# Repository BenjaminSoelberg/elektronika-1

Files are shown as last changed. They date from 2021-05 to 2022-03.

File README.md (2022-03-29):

# ELEKTRONIKA-1 - A replacement module for a USSR made vintage LED watch anno 1978

## It actually works
The watch works very well and I am very happy with it.

It has been my daily driver for a few months by now with no problems what so ever.

It can show time, date and year which was more or less what you got in the original.

The module is based around:
* Texas Instruments MSP430fr2433 micro controller
* Austria Micro Systems AS1115 64 bit LED driver
* Vintage Hewlett Packard HP-5082-7414 4x7 segments + dot display
* CR2032 battery

## Source code
Modules:

* buttons.c - This is the button driver and it handles button events 
* clocksystem.c - Initializes the clock system in the MSP430
* config.h - Global timing and clock constants
* debounce.c - The button debounce detection and filtering using a sliding bit buffer
* display.c - Display update functions like content and intensity.
* driverlib_ng.c - My overloading of the TI MSP430 driver lib for better pin handling
* elektronika.c - Handles the control flow of everything
* render.c - Simple 7 segment 'font' driver
* rtcclock.c - Realtime clock module supporting adjusting date and time
* utils.h - Macros for entering and exiting critical sections

Written using Code Composer Studio.

## Hardware

The PCB is designed in KiCad and is my first ever multi layer PCB.

Button contacts are made with what would normally be plated half castellated holes but they are in reality nothing more than partially routed mounting holes.

The AS1115 display driver was choosen as it is able to drive the LED display directly as well as adjusting the current.

A lot of care has been taken to save as much power as possible.  Battery life is messured to be around 10 years (less if you actually press buttons as the LED technology from the late 1970 uses a lot of current).

The watch uses around 0.002 mA/h in standby and 10-40 mA/h while the display is on.

Originally the two 1.55 V batteries didn't even last a year.

Schematics:

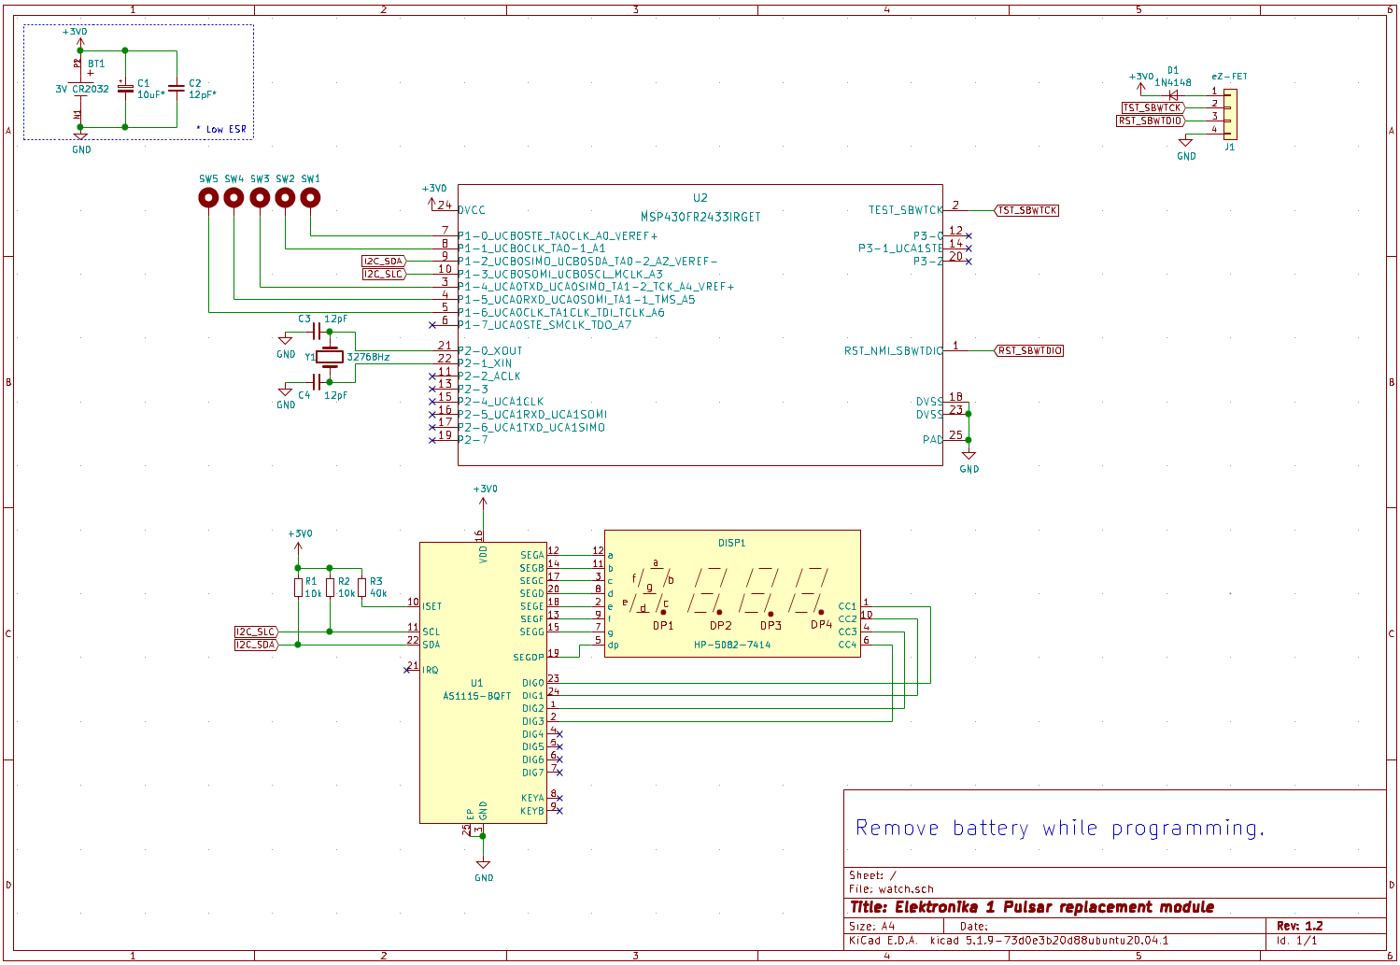
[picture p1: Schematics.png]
Schematics


The four PCB layers:

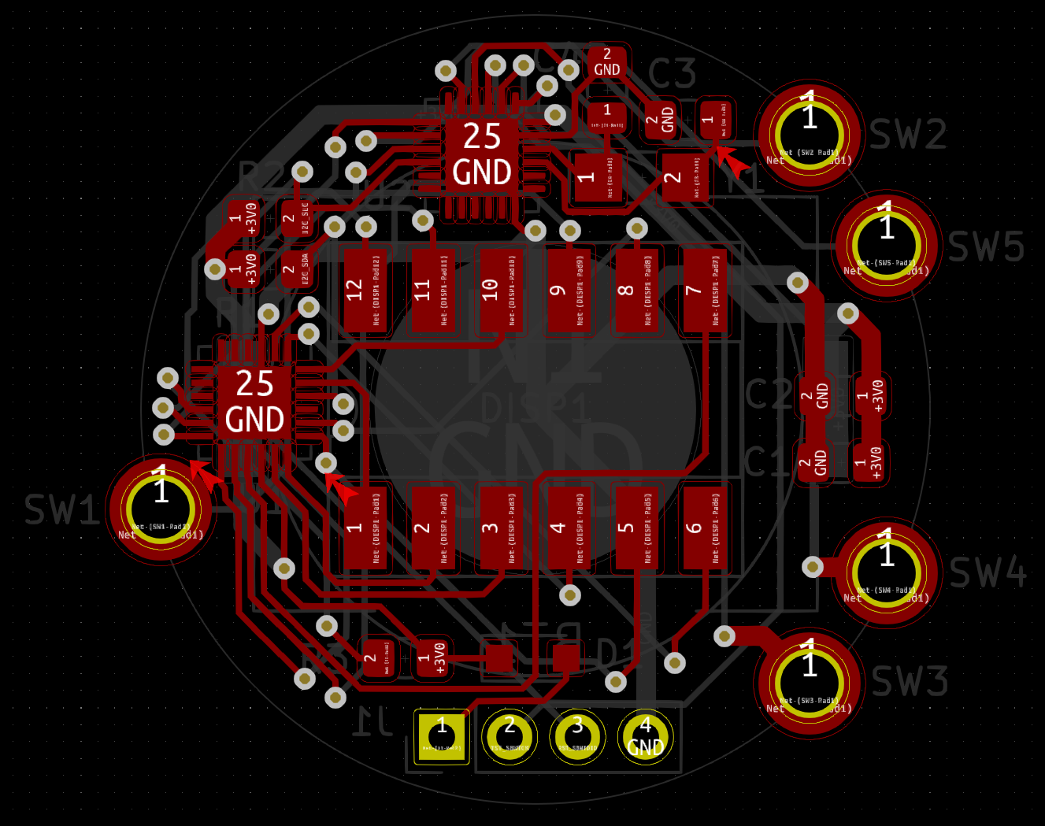
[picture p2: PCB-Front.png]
The four PCB layers


3D render of front PCB:

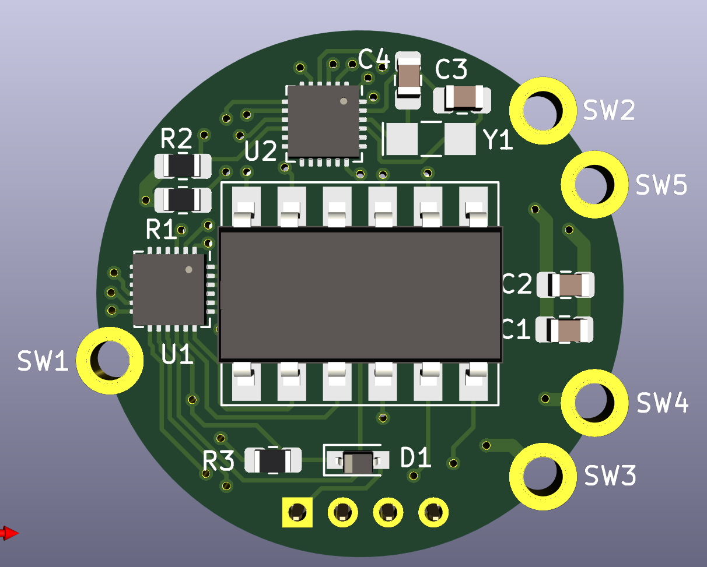
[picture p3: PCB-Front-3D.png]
3D render of front PCB


3D render of back PCB:

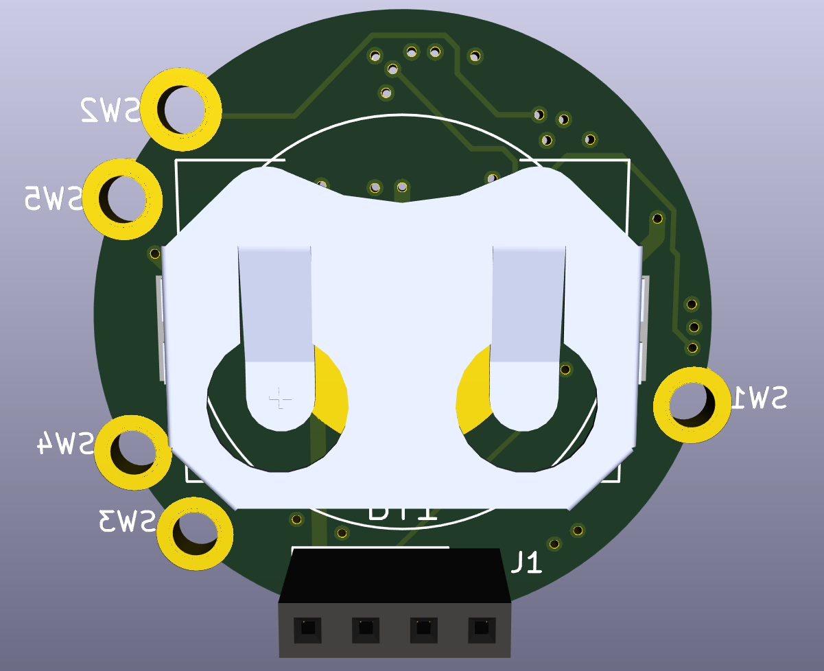
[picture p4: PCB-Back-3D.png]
3D render of back PCB


What the original module looks like:

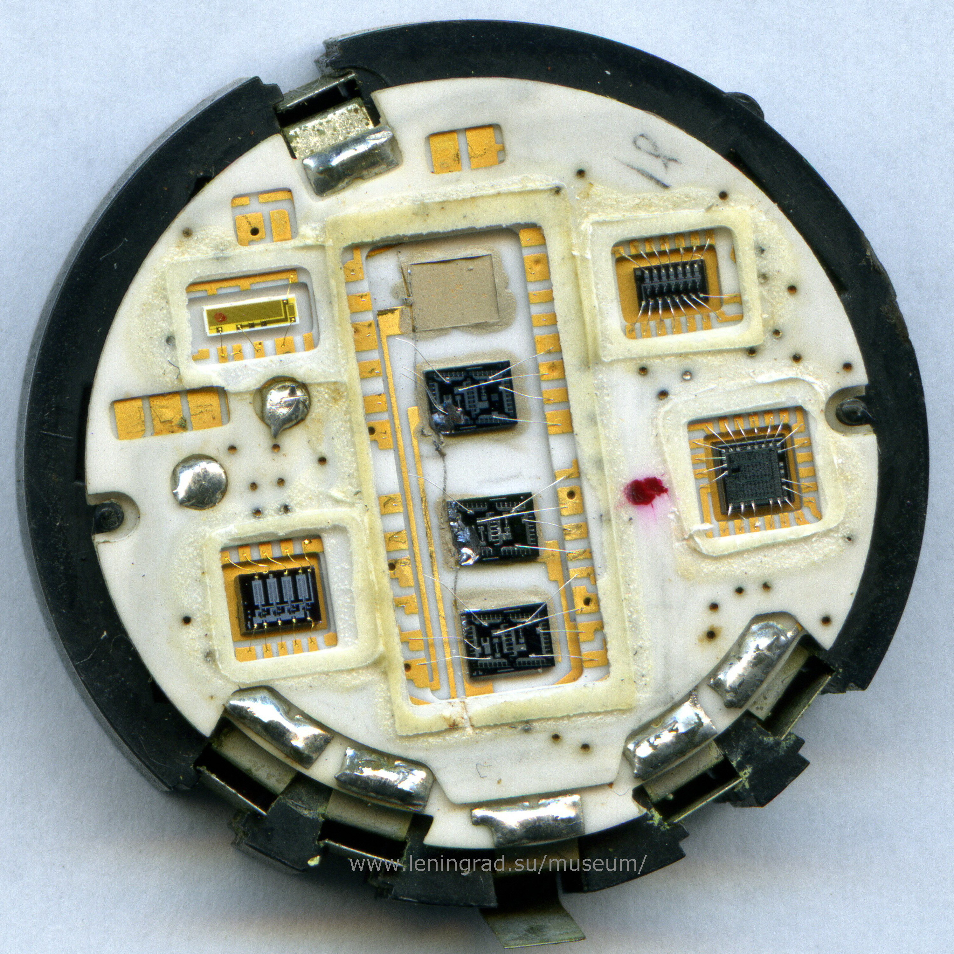
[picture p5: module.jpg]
Original module


New watch module:

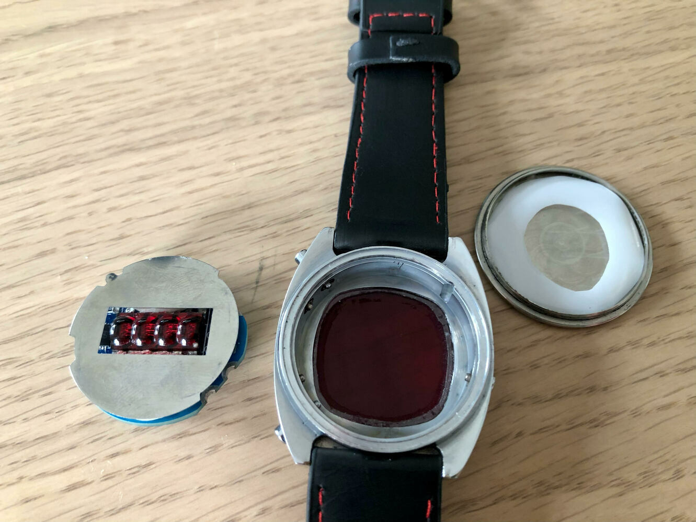
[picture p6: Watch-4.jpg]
Dissambled


New watch module installed:

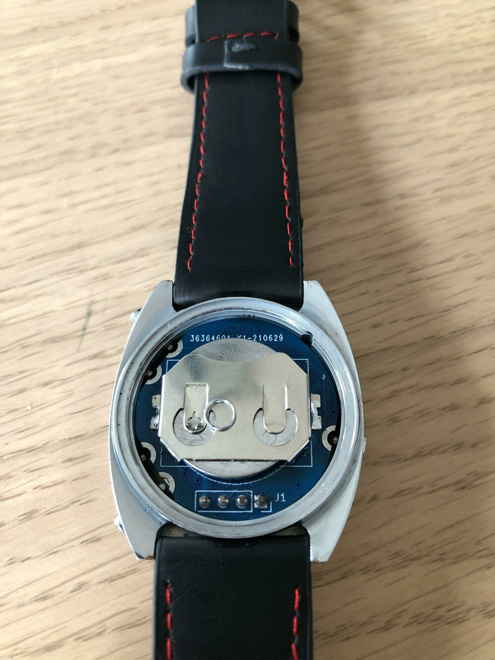
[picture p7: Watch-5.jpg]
New watch module


Showing time:

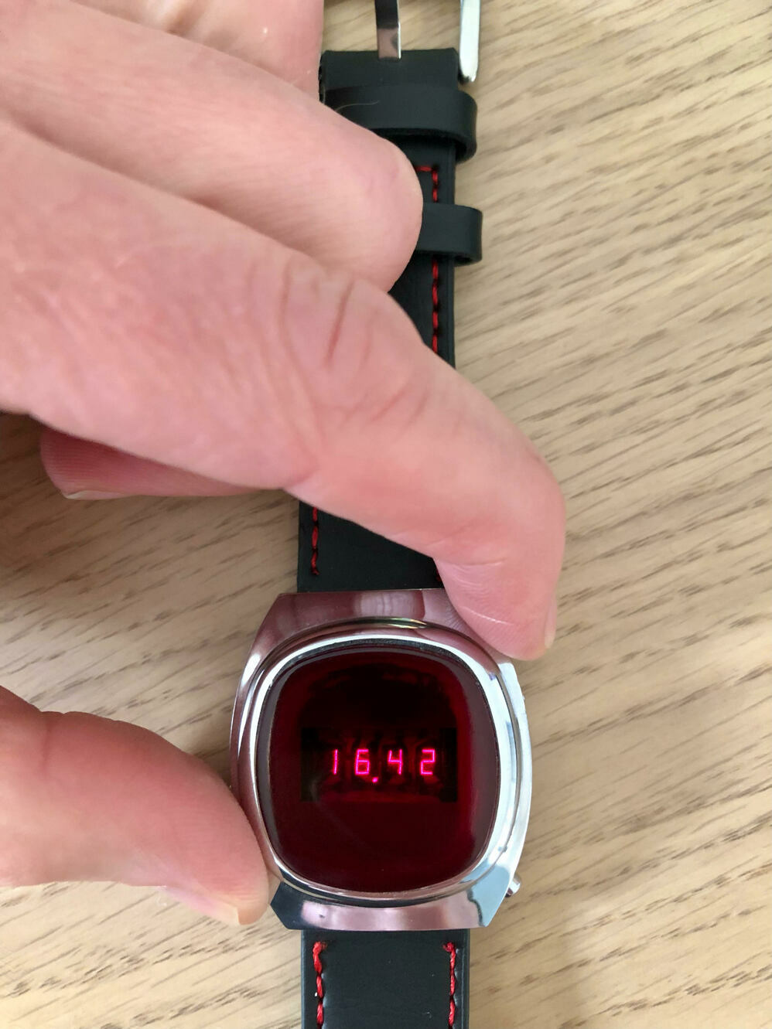
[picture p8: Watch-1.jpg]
Showing time


Showning date:

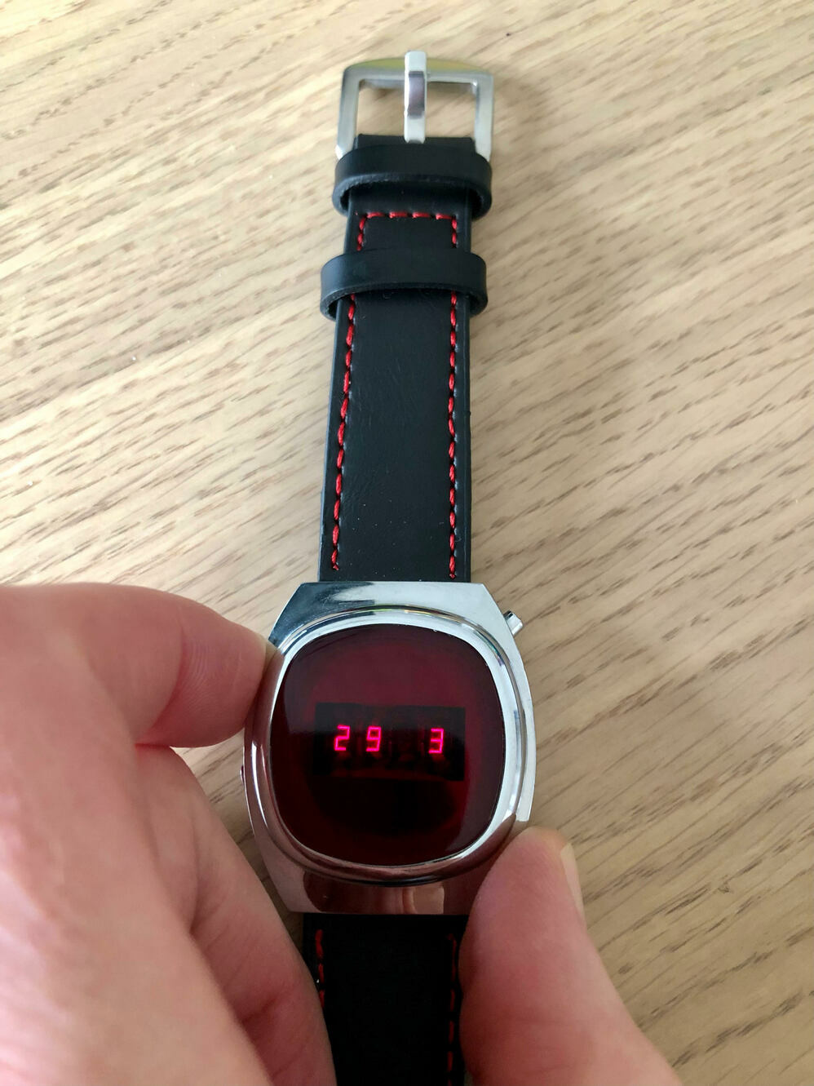
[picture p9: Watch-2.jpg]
Showning date


On wrist:

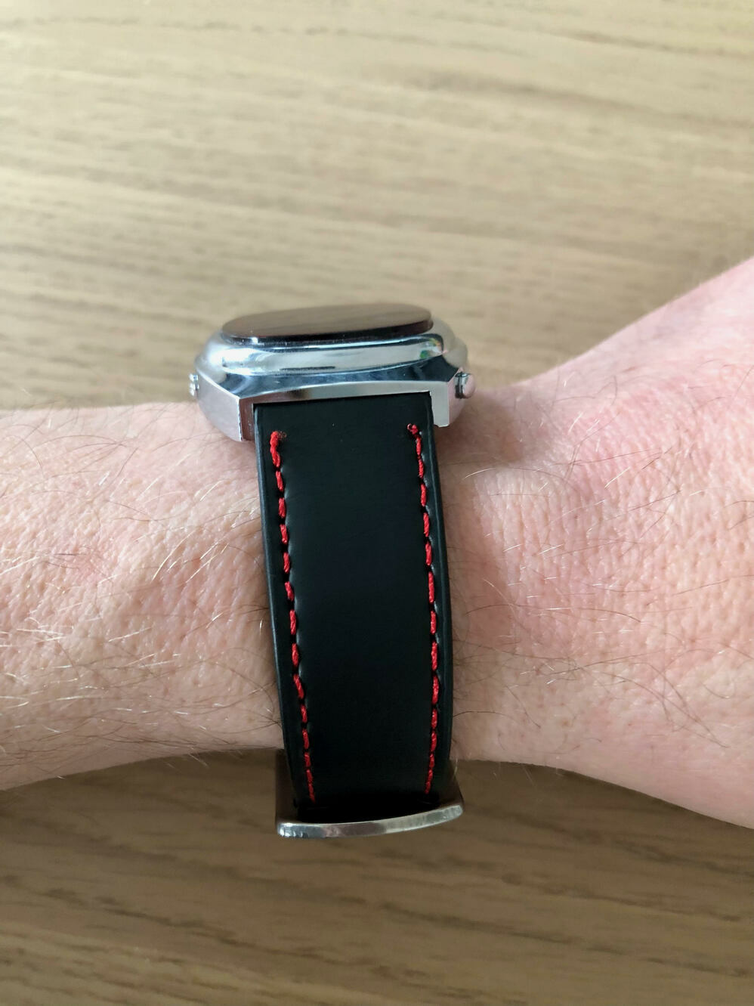
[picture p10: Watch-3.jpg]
On wrist


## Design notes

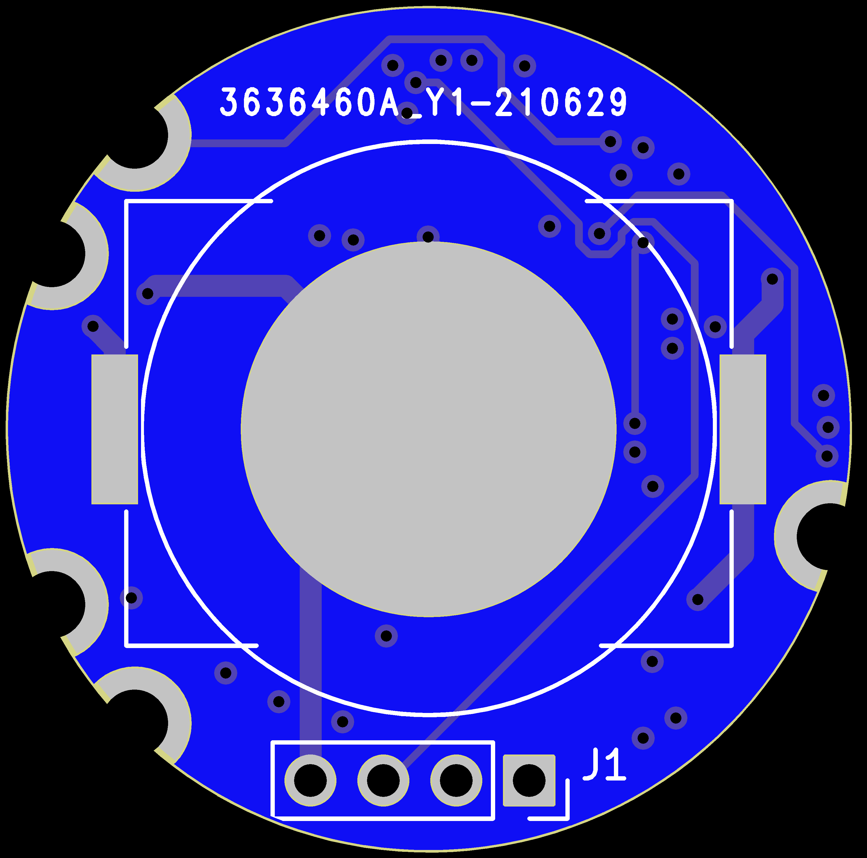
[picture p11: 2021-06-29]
JLCPCB/from-jlcpcb/jlc-back.png

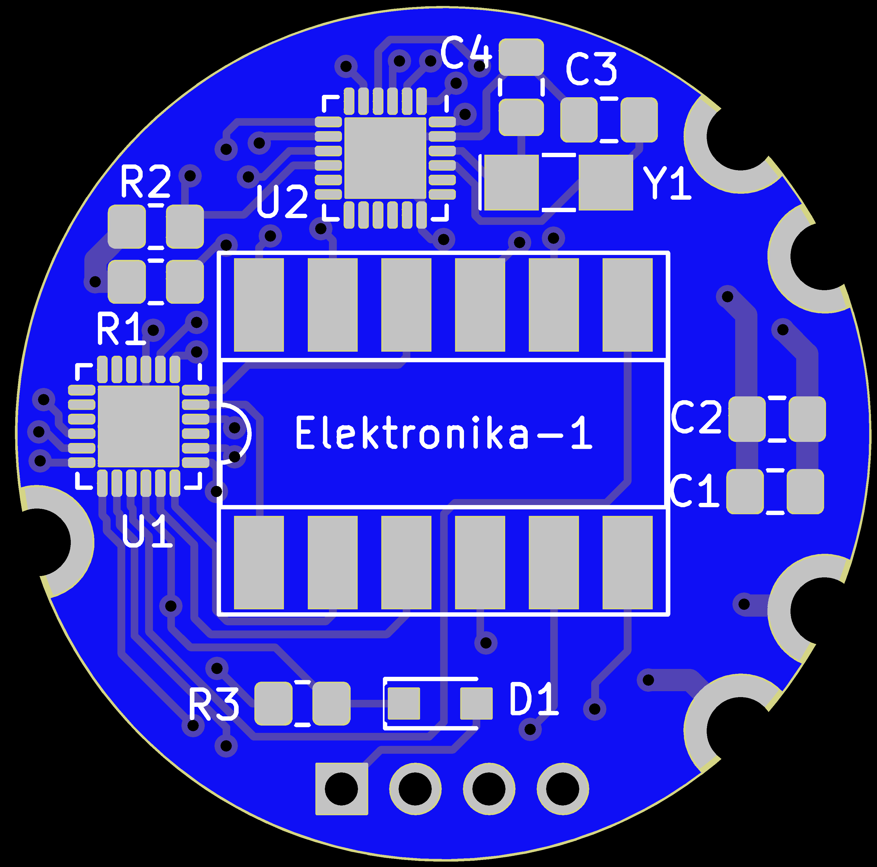
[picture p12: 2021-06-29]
JLCPCB/from-jlcpcb/jlc-front.png

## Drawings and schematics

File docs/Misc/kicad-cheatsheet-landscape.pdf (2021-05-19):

# cheatsheet

## 3) Create new components as necessary

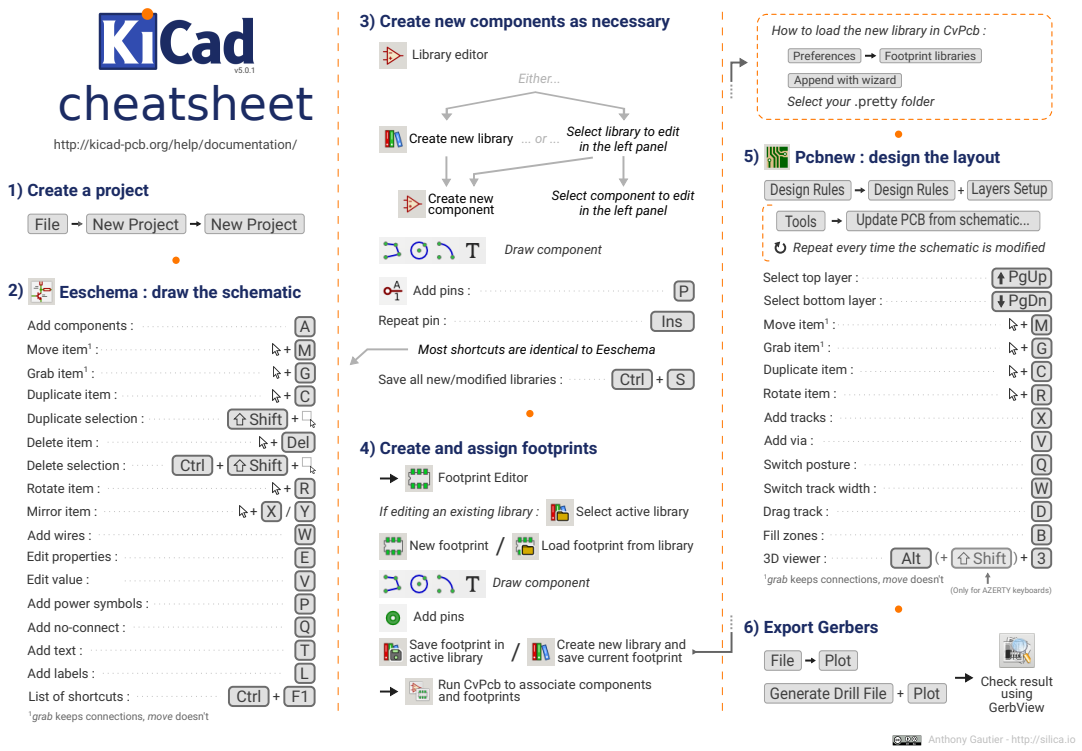
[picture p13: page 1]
1) Create a project; File; New Project; Add components :; Duplicate item :; Duplicate selection :; Shift +; Delete item :; + Del; Delete selection :; Ctrl; Shift ++; Rotate item :; Mirror item :; Add wires :; Edit properties :; Add power symbols :; Add no-connect :; Add text :; Add labels :; List of shortcuts :; Ctrl + F1; Edit value :; Draw component; Library editor; Repeat pin :; Ins; Save all new/modified libraries :; Ctrl + S; Create new component; Add pins :; Either...; Footprint Editor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

How to load the new library in CvPcb :
Append with wizard
Select your .pretty folder

Select library to edit

in the left panel Create new library

http://kicad-pcb.org/help/documentation/

5) Pcbnew : design the layout
Repeat every time the schematic is modified
Select top layer :
Move item¹
Grab item¹
Duplicate item :
Rotate item :
Add tracks :
Add via :
Switch posture :
Switch track width :
Drag track :
Fill zones :
3D viewer :
grab keeps connections, move doesn't

Select component to edit
in the left panel

2) Eeschema : draw the schematic

Most shortcuts are identical to Eeschema

4) Create and assign footprints

New footprint / Load footprint from library

(Only for AZERTY keyboards)

Add pins
Create new library and / save current footprint Save footprint in
active library
Run CvPcb to associate components
and footprints

6) Export Gerbers
Generate Drill File + Plot

Anthony Gautier - http://silica.io

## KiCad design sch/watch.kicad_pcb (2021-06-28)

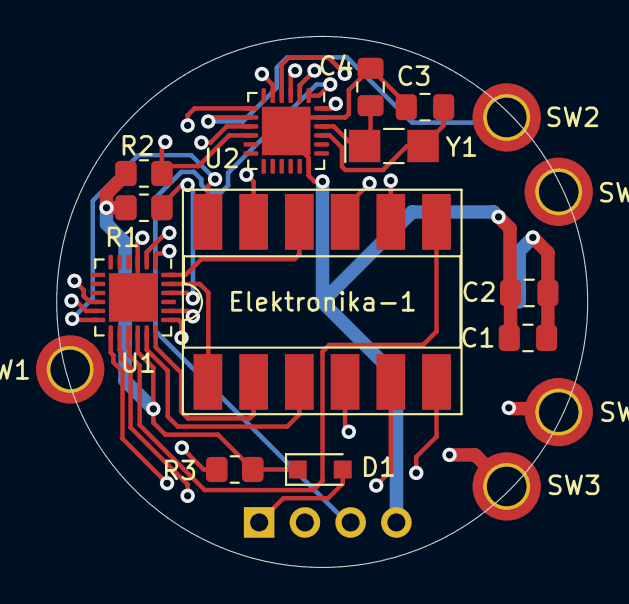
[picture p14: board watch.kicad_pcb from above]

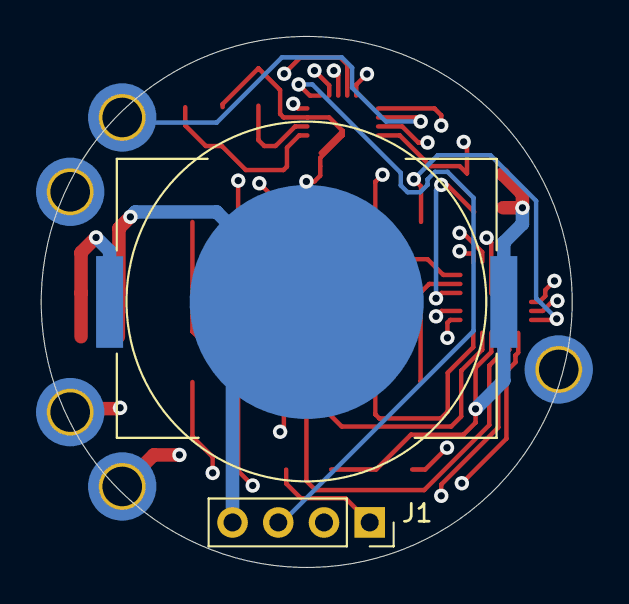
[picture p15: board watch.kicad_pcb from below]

Board: 4 copper layers, 29.5 x 29.5 mm, 19 parts (2 on the bottom side), 27 nets.

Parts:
BT1: 3V CR2032; BAT-HLD-001
C1: 10uF*; C_0805_2012Metric_Pad1.18x1.45mm_HandSolder
C2: 12pF*; C_0805_2012Metric_Pad1.18x1.45mm_HandSolder
C3, C4: 12pF; C_0805_2012Metric_Pad1.18x1.45mm_HandSolder
D1: 1N4148; D_SOD-323_HandSoldering
Elektronika-1: HP-5082-7414; DIP-12_W8.89mm_SMDSocket_LongPads
J1: eZ-FET; PinSocket_1x04_P2.54mm_Vertical
R1, R2: 10k; R_0805_2012Metric_Pad1.20x1.40mm_HandSolder
R3: 40k; R_0805_2012Metric_Pad1.20x1.40mm_HandSolder
SW1: SW1; MountingHole_2.2mm_M2_DIN965_Pad_TopBottom
SW2: SW2; MountingHole_2.2mm_M2_DIN965_Pad_TopBottom
SW3: SW3; MountingHole_2.2mm_M2_DIN965_Pad_TopBottom
SW4: SW4; MountingHole_2.2mm_M2_DIN965_Pad_TopBottom
SW5: SW5; MountingHole_2.2mm_M2_DIN965_Pad_TopBottom
U1: AS1115; QFN-24-1EP_4x4mm_P0.5mm_EP2.7x2.7mm
U2: MSP430FR2433; QFN-24-1EP_4x4mm_P0.5mm_EP2.7x2.7mm
Y1: 32768Hz; Crystal_SMD_MicroCrystal_CC7V-T1A-2Pin_3.2x1.5mm_HandSolder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

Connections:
+3V0: BT1.P1, BT1.P2, C1.1, C2.1, D1.1, R1.1, R2.1, R3.1, U1.16, U2.24
GND: BT1.N1, C1.2, C2.2, C3.2, C4.2, J1.4, U1.3, U1.25, U2.18, U2.23, U2.25
I2C_SDA: R1.2, U1.22, U2.9
I2C_SLC: R2.2, U1.11, U2.10
unnamed: C3.1, U2.21, Y1.2
unnamed: C4.1, U2.22, Y1.1
unnamed: D1.2, J1.1
unnamed: Elektronika-1.1, U1.23
unnamed: Elektronika-1.2, U1.18
unnamed: Elektronika-1.3, U1.17
unnamed: Elektronika-1.4, U1.1
unnamed: Elektronika-1.5, U1.19
unnamed: Elektronika-1.6, U1.2
unnamed: Elektronika-1.7, U1.15
unnamed: Elektronika-1.8, U1.20
unnamed: Elektronika-1.9, U1.13
unnamed: Elektronika-1.10, U1.24
unnamed: Elektronika-1.11, U1.14
unnamed: Elektronika-1.12, U1.12
unnamed: R3.2, U1.10
unnamed: SW1.1, U2.7
unnamed: SW2.1, U2.8
unnamed: SW3.1, U2.3
unnamed: SW4.1, U2.4
unnamed: SW5.1, U2.5
RST_SBWTDIO: J1.3, U2.1
TST_SBWTCK: J1.2, U2.2

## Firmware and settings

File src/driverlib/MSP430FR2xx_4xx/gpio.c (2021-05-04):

//*****************************************************************************
//
// gpio.c - Driver for the gpio Module.
//
//*****************************************************************************

//*****************************************************************************
//
//! \addtogroup gpio_api gpio
//! @{
//
//*****************************************************************************

#include "inc/hw_memmap.h"

#if defined(__MSP430_HAS_PORT1_R__) || defined(__MSP430_HAS_PORT2_R__) ||\
    defined(__MSP430_HAS_PORTA_R__)
#include "gpio.h"

#include <assert.h>

static const uint16_t GPIO_PORT_TO_BASE[] = {
    0x00,
#if defined(__MSP430_HAS_PORT1_R__)
    __MSP430_BASEADDRESS_PORT1_R__,
#elif defined(__MSP430_HAS_PORT1__)
    __MSP430_BASEADDRESS_PORT1__,
#else
    0xFFFF,
#endif
#if defined(__MSP430_HAS_PORT2_R__)
    __MSP430_BASEADDRESS_PORT2_R__,
#elif defined(__MSP430_HAS_PORT2__)
    __MSP430_BASEADDRESS_PORT2__,
#else
    0xFFFF,
#endif
#if defined(__MSP430_HAS_PORT3_R__)
    __MSP430_BASEADDRESS_PORT3_R__,
#elif defined(__MSP430_HAS_PORT3__)
    __MSP430_BASEADDRESS_PORT3__,
#else
    0xFFFF,
#endif
#if defined(__MSP430_HAS_PORT4_R__)
    __MSP430_BASEADDRESS_PORT4_R__,
#elif defined(__MSP430_HAS_PORT4__)
    __MSP430_BASEADDRESS_PORT4__,
#else
    0xFFFF,
#endif
#if defined(__MSP430_HAS_PORT5_R__)
    __MSP430_BASEADDRESS_PORT5_R__,
#elif defined(__MSP430_HAS_PORT5__)
    __MSP430_BASEADDRESS_PORT5__,
#else
    0xFFFF,
#endif
#if defined(__MSP430_HAS_PORT6_R__)
    __MSP430_BASEADDRESS_PORT6_R__,
#elif defined(__MSP430_HAS_PORT6__)
    __MSP430_BASEADDRESS_PORT6__,
#else
    0xFFFF,
#endif
#if defined(__MSP430_HAS_PORT7_R__)
    __MSP430_BASEADDRESS_PORT7_R__,
#elif defined(__MSP430_HAS_PORT7__)
    __MSP430_BASEADDRESS_PORT7__,
#else
    0xFFFF,
#endif
#if defined(__MSP430_HAS_PORT8_R__)
    __MSP430_BASEADDRESS_PORT8_R__,
#elif defined(__MSP430_HAS_PORT8__)
    __MSP430_BASEADDRESS_PORT8__,
#else
    0xFFFF,
#endif
#if defined(__MSP430_HAS_PORT9_R__)
    __MSP430_BASEADDRESS_PORT9_R__,
#elif defined(__MSP430_HAS_PORT9__)
    __MSP430_BASEADDRESS_PORT9__,
#else
    0xFFFF,
#endif
#if defined(__MSP430_HAS_PORT10_R__)
    __MSP430_BASEADDRESS_PORT10_R__,
#elif defined(__MSP430_HAS_PORT10__)
    __MSP430_BASEADDRESS_PORT10__,
#else
    0xFFFF,
#endif
#if defined(__MSP430_HAS_PORT11_R__)
    __MSP430_BASEADDRESS_PORT11_R__,
#elif defined(__MSP430_HAS_PORT11__)
    __MSP430_BASEADDRESS_PORT11__,
#else
    0xFFFF,
#endif
    0xFFFF,
#if defined(__MSP430_HAS_PORTJ_R__)
    __MSP430_BASEADDRESS_PORTJ_R__
#elif defined(__MSP430_HAS_PORTJ__)
    __MSP430_BASEADDRESS_PORTJ__
#else
    0xFFFF
#endif
};

void GPIO_setAsOutputPin(uint8_t selectedPort, uint16_t selectedPins) {

    uint16_t baseAddress = GPIO_PORT_TO_BASE[selectedPort];

    #ifndef NDEBUG
    if(baseAddress == 0xFFFF) {
        return;
    }
    #endif

    // Shift by 8 if port is even (upper 8-bits)
    if((selectedPort & 1) ^ 1) {
        selectedPins <<= 8;
    }

#ifdef __MSP430_HAS_PASEL0__
    HWREG16(baseAddress + OFS_PASEL0) &= ~selectedPins;
#endif
#ifdef __MSP430_HAS_PASEL1__
    HWREG16(baseAddress + OFS_PASEL1) &= ~selectedPins;
#endif
    HWREG16(baseAddress + OFS_PADIR) |= selectedPins;

    return;
}

void GPIO_setAsInputPin(uint8_t selectedPort, uint16_t selectedPins) {

    uint16_t baseAddress = GPIO_PORT_TO_BASE[selectedPort];

    #ifndef NDEBUG
    if(baseAddress == 0xFFFF) {
        return;
    }
    #endif

    // Shift by 8 if port is even (upper 8-bits)
    if((selectedPort & 1) ^ 1) {
        selectedPins <<= 8;
    }

#ifdef __MSP430_HAS_PASEL0__
    HWREG16(baseAddress + OFS_PASEL0) &= ~selectedPins;
#endif
#ifdef __MSP430_HAS_PASEL1__
    HWREG16(baseAddress + OFS_PASEL1) &= ~selectedPins;
#endif
    HWREG16(baseAddress + OFS_PADIR) &= ~selectedPins;
    HWREG16(baseAddress + OFS_PAREN) &= ~selectedPins;
}
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

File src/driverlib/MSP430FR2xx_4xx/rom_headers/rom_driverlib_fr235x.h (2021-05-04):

//*****************************************************************************
//
// rom_driverlib_fr235x.h - Macros to facilitate calling functions in ROM for
// MSP430FR2355, FR2353, FR2153, FR2155
//
// Copyright (c) 2017 Texas Instruments Incorporated.  All rights reserved.
// TI Information - Selective Disclosure
//
//*****************************************************************************
//

#if defined(__TI_COMPILER_VERSION__)
#if __TI_COMPILER_VERSION__ >= 18001001
#define __cc_rom __attribute__((call_conv("cc_rom")))
#else
#error "The cc_rom attribute requires MSP TI COMPILER 18.1.1.LTS or more recent."
#endif  // __TI_COMPILER_VERSION__ >= 
#endif  // (defined(__TI_COMPILER_VERSION__))18001001

#if defined(__IAR_SYSTEMS_ICC__) && (__VER__ < 650)
#error "The __cc_rom attribute requires IAR version 6.50 or more recent."
#endif

#if __REGISTER_R4__ != __REGISTER_FREE__
#error "Incorrect setting for R4, expected it to be free."
#endif

#if __REGISTER_R5__ != __REGISTER_FREE__
#error "Incorrect setting for R5, expected it to be free."
#endif

// Suppress type conversion warning
#ifdef __TI_COMPILER_VERSION__
#pragma diag_suppress 173
#endif

#if (defined(__TI_COMPILER_VERSION__) && !defined(__LARGE_DATA_MODEL__)) || \
(defined(__IAR_SYSTEMS_ICC__) && (__DATA_MODEL__!=__DATA_MODEL_LARGE__))
#error "Only large data model supported for this ROM."
#endif

#ifndef __ROM_DRIVERLIB_H__
#define __ROM_DRIVERLIB_H__

#if (defined(__TI_COMPILER_VERSION__) && defined(__LARGE_CODE_MODEL__)) || \
    (defined(__IAR_SYSTEMS_ICC__) && (__CODE_MODEL__==__CODE_MODEL_LARGE__))

//*****************************************************************************
//
// Pointers to the main API tables.
//
//*****************************************************************************
#ifndef ROM_TABLE
#define ROM_TABLE                      ((uint32_t *)ROMLIB_START)
#endif
#define ROM_DRIVERLIB_APITABLE         ((uint32_t *)&ROM_TABLE[2])
#define ROM_DRIVERLIB_VERSIONL         (ROM_DRIVERLIB_APITABLE[0])
#define ROM_DRIVERLIB_VERSIONH         (ROM_DRIVERLIB_APITABLE[1])
#define ROM_ADCTABLE                   ((uint32_t *)(ROM_DRIVERLIB_APITABLE[2]))
#define ROM_CRCTABLE                   ((uint32_t *)(ROM_DRIVERLIB_APITABLE[3]))
#define ROM_CSTABLE                    ((uint32_t *)(ROM_DRIVERLIB_APITABLE[4]))
#define ROM_ECOMPTABLE                 ((uint32_t *)(ROM_DRIVERLIB_APITABLE[5]))
#define ROM_EUSCIASPITABLE             ((uint32_t *)(ROM_DRIVERLIB_APITABLE[6]))
#define ROM_EUSCIAUARTTABLE            ((uint32_t *)(ROM_DRIVERLIB_APITABLE[7]))
#define ROM_EUSCIBI2CTABLE             ((uint32_t *)(ROM_DRIVERLIB_APITABLE[8]))
#define ROM_EUSCIBSPITABLE             ((uint32_t *)(ROM_DRIVERLIB_APITABLE[9]))
#define ROM_FRAMCTLTABLE               ((uint32_t *)(ROM_DRIVERLIB_APITABLE[10]))
#define ROM_GPIOTABLE                  ((uint32_t *)(ROM_DRIVERLIB_APITABLE[11]))
#define ROM_ICCTABLE                   ((uint32_t *)(ROM_DRIVERLIB_APITABLE[12]))
#define ROM_MPY32TABLE                 ((uint32_t *)(ROM_DRIVERLIB_APITABLE[14]))
#define ROM_PMMTABLE                   ((uint32_t *)(ROM_DRIVERLIB_APITABLE[15]))
#define ROM_RTCTABLE                   ((uint32_t *)(ROM_DRIVERLIB_APITABLE[16]))
#define ROM_SACTABLE                   ((uint32_t *)(ROM_DRIVERLIB_APITABLE[17]))
#define ROM_SFRTABLE                   ((uint32_t *)(ROM_DRIVERLIB_APITABLE[18]))
#define ROM_SYSCTLTABLE                ((uint32_t *)(ROM_DRIVERLIB_APITABLE[19]))
#define ROM_TIMER_BTABLE               ((uint32_t *)(ROM_DRIVERLIB_APITABLE[22]))
#define ROM_TLVTABLE                   ((uint32_t *)(ROM_DRIVERLIB_APITABLE[23]))
#define ROM_WDTATABLE                  ((uint32_t *)(ROM_DRIVERLIB_APITABLE[24]))

#define ROM_DRIVERLIB_getVersion()     ((uint32_t)ROM_DRIVERLIB_VERSIONH<<16|\
                                            ROM_DRIVERLIB_VERSIONL)
#ifndef ROM_getVersion
#define ROM_getVersion()               ((uint32_t)(ROMLIB_START[0]))
#endif

//*****************************************************************************
//
// Macros for calling ROM functions in the ADC API.
//
//*****************************************************************************

#define ROM_ADC_init                                                          \
        ((void ( __cc_rom *)(uint16_t baseAddress,                            \
                             uint16_t sampleHoldSignalSourceSelect,           \
                             uint8_t clockSourceSelect,                       \
                             uint16_t clockSourceDivider))ROM_ADCTABLE[0])

#define ROM_ADC_enable                                                        \
        ((void ( __cc_rom *)(uint16_t baseAddress))ROM_ADCTABLE[1])

#define ROM_ADC_disable                                                       \
        ((void ( __cc_rom *)(uint16_t baseAddress))ROM_ADCTABLE[2])

#define ROM_ADC_setupSamplingTimer                                            \
        ((void ( __cc_rom *)(uint16_t baseAddress,                            \
                             uint16_t clockCycleHoldCount,                    \
                             uint16_t multipleSamplesEnabled))ROM_ADCTABLE[3])

#define ROM_ADC_disableSamplingTimer                                          \
        ((void ( __cc_rom *)(uint16_t baseAddress))ROM_ADCTABLE[4])

#define ROM_ADC_configureMemory                                               \
        ((void ( __cc_rom *)(uint16_t baseAddress,                            \
                             uint8_t inputSourceSelect,                       \
                             uint8_t positiveRefVoltageSourceSelect,          \
                             uint8_t negativeRefVoltageSourceSelect))ROM_ADCTABLE[5])

#define ROM_ADC_enableInterrupt                                               \
        ((void ( __cc_rom *)(uint16_t baseAddress,                            \
                             uint8_t interruptMask))ROM_ADCTABLE[6])

#define ROM_ADC_disableInterrupt                                              \
        ((void ( __cc_rom *)(uint16_t baseAddress,                            \
                             uint8_t interruptMask))ROM_ADCTABLE[7])

#define ROM_ADC_clearInterrupt                                                \
        ((void ( __cc_rom *)(uint16_t baseAddress,                            \
                             uint8_t interruptFlagMask))ROM_ADCTABLE[8])

#define ROM_ADC_getInterruptStatus                                            \
        ((uint8_t ( __cc_rom *)(uint16_t baseAddress,                         \
                                uint8_t interruptFlagMask))ROM_ADCTABLE[9])

#define ROM_ADC_startConversion                                               \
        ((void ( __cc_rom *)(uint16_t baseAddress,                            \
                             uint8_t conversionSequenceModeSelect))ROM_ADCTABLE[10])
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

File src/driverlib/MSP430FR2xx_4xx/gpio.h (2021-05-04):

//*****************************************************************************
//
// gpio.h - Driver for the GPIO Module.
//
//*****************************************************************************

#ifndef __MSP430WARE_GPIO_H__
#define __MSP430WARE_GPIO_H__

#include "inc/hw_memmap.h"

#if defined(__MSP430_HAS_PORT1_R__) || defined(__MSP430_HAS_PORT2_R__) ||\
    defined(__MSP430_HAS_PORTA_R__)

//*****************************************************************************
//
// If building with a C++ compiler, make all of the definitions in this header
// have a C binding.
//
//*****************************************************************************
#ifdef __cplusplus
extern "C"
{
#endif

//*****************************************************************************
//
// The following are values that can be passed to the selectedPort parameter
// for functions: GPIO_setAsOutputPin(), GPIO_setAsInputPin(),
// GPIO_setAsPeripheralModuleFunctionOutputPin(),
// GPIO_setAsPeripheralModuleFunctionInputPin(), GPIO_setOutputHighOnPin(),
// GPIO_setOutputLowOnPin(), GPIO_toggleOutputOnPin(),
// GPIO_setAsInputPinWithPullDownResistor(),
// GPIO_setAsInputPinWithPullUpResistor(), GPIO_getInputPinValue(),
// GPIO_selectInterruptEdge(), GPIO_enableInterrupt(), GPIO_disableInterrupt(),
// GPIO_getInterruptStatus(), and GPIO_clearInterrupt().
//
//*****************************************************************************
#define GPIO_PORT_P1                                                          1
#define GPIO_PORT_P2                                                          2
#define GPIO_PORT_P3                                                          3
#define GPIO_PORT_P4                                                          4
#define GPIO_PORT_P5                                                          5
#define GPIO_PORT_P6                                                          6
#define GPIO_PORT_P7                                                          7
#define GPIO_PORT_P8                                                          8
#define GPIO_PORT_P9                                                          9
#define GPIO_PORT_P10                                                        10
#define GPIO_PORT_P11                                                        11
#define GPIO_PORT_PA                                                          1
#define GPIO_PORT_PB                                                          3
#define GPIO_PORT_PC                                                          5
#define GPIO_PORT_PD                                                          7
#define GPIO_PORT_PE                                                          9
#define GPIO_PORT_PF                                                         11
#define GPIO_PORT_PJ                                                         13
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

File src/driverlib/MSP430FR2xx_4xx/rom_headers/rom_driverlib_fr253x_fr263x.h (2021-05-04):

//*****************************************************************************
//
// rom_driverlib_fr253x_fr263x.h - Macros to facilitate calling functions in 
// ROM for MSP430FR2532, FR2533, FR2632, FR2633
//
// Copyright (c) 2014-2017 Texas Instruments Incorporated.  All rights reserved.
// TI Information - Selective Disclosure
//
//*****************************************************************************
//

#ifndef __ROM_DRIVERLIB_H__
#define __ROM_DRIVERLIB_H__

#if (defined(__TI_COMPILER_VERSION__) && !defined(__LARGE_CODE_MODEL__)) || \
    (defined(__IAR_SYSTEMS_ICC__) && (__CODE_MODEL__==__CODE_MODEL_SMALL__))

//*****************************************************************************
//
// Pointers to the main API tables.
//
//*****************************************************************************
#define ROM_DRIVERLIB_APITABLE         ((uint16_t *)0x67E0)
#define ROM_DRIVERLIB_VERSIONL         (ROM_DRIVERLIB_APITABLE[0])
#define ROM_DRIVERLIB_VERSIONH         (ROM_DRIVERLIB_APITABLE[1])
#define ROM_EUSCIASPITABLE             ((uint16_t *)(ROM_DRIVERLIB_APITABLE[2]))
#define ROM_EUSCIAUARTTABLE            ((uint16_t *)(ROM_DRIVERLIB_APITABLE[3]))
#define ROM_EUSCIBI2CTABLE             ((uint16_t *)(ROM_DRIVERLIB_APITABLE[4]))
#define ROM_EUSCIBSPITABLE             ((uint16_t *)(ROM_DRIVERLIB_APITABLE[5]))

#define ROM_DRIVERLIB_getVersion()     ((uint32_t)ROM_DRIVERLIB_VERSIONH<<16|\
                                            ROM_DRIVERLIB_VERSIONL)

//*****************************************************************************
//
// Macros for calling ROM functions in the EUSCIASPI API.
//
//*****************************************************************************
#define ROM_EUSCI_A_SPI_disableInterrupt                                      \
        ((void (*)(uint16_t baseAddress,                                      \
                   uint8_t mask))ROM_EUSCIASPITABLE[0])
#define ROM_EUSCI_A_SPI_disable                                               \
        ((void (*)(uint16_t baseAddress))ROM_EUSCIASPITABLE[1])
#define ROM_EUSCI_A_SPI_isBusy                                                \
        ((uint16_t (*)(uint16_t baseAddress))ROM_EUSCIASPITABLE[2])
#define ROM_EUSCI_A_SPI_getReceiveBufferAddress                               \
        ((uint32_t (*)(uint16_t baseAddress))ROM_EUSCIASPITABLE[3])
#define ROM_EUSCI_A_SPI_enableInterrupt                                       \
        ((void (*)(uint16_t baseAddress,                                      \
                   uint8_t mask))ROM_EUSCIASPITABLE[4])
#define ROM_EUSCI_A_SPI_transmitData                                          \
        ((void (*)(uint16_t baseAddress,                                      \
                   uint8_t transmitData))ROM_EUSCIASPITABLE[5])
#define ROM_EUSCI_A_SPI_changeMasterClock                                     \
        ((void (*)(uint16_t baseAddress,                                      \
                   EUSCI_A_SPI_changeMasterClockParam *param))ROM_EUSCIASPITABLE[6])
#define ROM_EUSCI_A_SPI_initMaster                                            \
        ((void (*)(uint16_t baseAddress,                                      \
                   EUSCI_A_SPI_initMasterParam *param))ROM_EUSCIASPITABLE[7])
#define ROM_EUSCI_A_SPI_changeClockPhasePolarity                              \
        ((void (*)(uint16_t baseAddress,                                      \
                   uint16_t clockPhase,                                       \
                   uint16_t clockPolarity))ROM_EUSCIASPITABLE[8])
#define ROM_EUSCI_A_SPI_getInterruptStatus                                    \
        ((uint8_t (*)(uint16_t baseAddress,                                   \
                      uint8_t mask))ROM_EUSCIASPITABLE[9])
#define ROM_EUSCI_A_SPI_select4PinFunctionality                               \
        ((void (*)(uint16_t baseAddress,                                      \
                   uint8_t select4PinFunctionality))ROM_EUSCIASPITABLE[10])
#define ROM_EUSCI_A_SPI_initSlave                                             \
        ((void (*)(uint16_t baseAddress,                                      \
                   EUSCI_A_SPI_initSlaveParam *param))ROM_EUSCIASPITABLE[11])
#define ROM_EUSCI_A_SPI_enable                                                \
        ((void (*)(uint16_t baseAddress))ROM_EUSCIASPITABLE[12])
#define ROM_EUSCI_A_SPI_getTransmitBufferAddress                              \
        ((uint32_t (*)(uint16_t baseAddress))ROM_EUSCIASPITABLE[13])
#define ROM_EUSCI_A_SPI_clearInterrupt                                        \
        ((void (*)(uint16_t baseAddress,                                      \
                   uint8_t mask))ROM_EUSCIASPITABLE[14])
#define ROM_EUSCI_A_SPI_receiveData                                           \
        ((uint8_t (*)(uint16_t baseAddress))ROM_EUSCIASPITABLE[15])
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

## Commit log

2021-05-13 added a wip button driver, display drivet etc
2021-05-13 working on button driver
2021-05-14 Added an empty button driver, and a initial display driver, all still untested
2021-05-19 Fixed a very annoying bug where writing to port one overwrote port two. The bug were caused by copy and pasting code from original driverlib. Took way to long to find...
    removed the blink test code from buttons and rtc as well as moved to ext 32khz crystal as osc
    added a WIP version of the schematics as well as moved stuff around. Also added some datasheet PDFs
    [watch.kicad_pcb, watch.sch]
2021-05-23 Added a new clocksystem module following the same format as other modules like the display and button driver. Updated the display driver to use AS1115 i2c driver chip to move multiplexing away from t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
    [watch.sch]
2021-06-02 Added a new button system
2021-06-05 Changed minimal button press response time to 100ms.\nFixed bug button driver
    [buttons.c, buttons.h]
2021-06-10 Added a (simple) button repeating handler. Added debug config options, button handling and display as well as i2c dummy stubs. Added setting of time and date handlinging
2021-06-17 updated schematic and pcb as well as component libs
2021-06-27 Updated the PCB
    [watch.kicad_pcb, watch.sch]
2021-06-27 Added schematics
    [watch.kicad_pcb]
2021-06-28 Added production files that was uploaded to JLCPCB.com
    [watch-B_Cu.gbr, watch-B_Mask.gbr, watch-B_Paste.gbr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]
2021-06-29 added JLCPCB production files
    [watch-B_Cu.gbr, watch-B_Mask.gbr, watch-B_Paste.gbr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]
2021-08-29 Fixed a bad and untested i2c configuration now that I actually have a real AS1115 chip to test with
    [clocksystem.c]
2021-08-31 Fixed old display content shown for a brief time upon Display_start call
    [buttons.h]
2021-09-09 Added startup display animation Fixed button pins from pullup to pulldown (The watch case will be connected to the positive battery terminal) Fixed button interrupt from port2 (which it is on the lau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
    [buttons.c, buttons.h]
2021-09-09 Added intensity adjustment via the SET_H and SET_L buttons
2021-09-11 Added a simple i2c timeout detection with automatic reboot Added a blinking dot while showing time
